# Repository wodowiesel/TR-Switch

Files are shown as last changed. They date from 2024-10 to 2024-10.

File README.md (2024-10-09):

# TR-Switch

The TX/RX-switch is a tool for signal sensitive or PTT switching for HAM radios incl. pcb schematics.

## DISCLAIMERS

**This is still "work-in-progress (WIP)" so I do NOT take any kind of responsibility for damages/data losses!**

**You can use this at your own risk without guarantees and put device on non conductive surface or enclosure!**

If you like the new design yo are free to share it!

Have fun :)

## HARDWARE

- 1x Custom PCB by WodoWiesel

- 1x USB-X cable for power supply

- 1x THT-SPDT relay +5V

- 3x THT-BNC female socket connector

- 1x THT-1N4001 flyback suppression diode

- 1x THT-2N3904 (TO-92) BJT transistor

- 3x THT-LED green+orange+red (tx/rx/pwr-indicator)

- 2x THT variable resistors 3-pin (~50-1kOhm)

- 1x THT-3.5mm socket (optional)

- 1x cable for PTT (optional)

- 1x enclosure/box (recommended)

- 1x Soldering iron

- Solder + flux + IPA

## SOFTWARE

No need for that.

## HOW TO USE

1. set up antenna, LNA, Transceiver and cables & adapters

2. connect PTT (optional)

3. turn on +5V power supply

4. Have Fun 73

## CREDITS

:copyright: 10/10/2023 WodoWiesel

Github (https://github.com/wodowiesel/)

Twitch (https://www.twitch.com/wodowiesel/)

Instagram (https://www.instagram.com/wodowiesel/)

YT (https://www.youtube.com/@wodowiesel/)

E-Mail (wodowiesel@quantentunnel.de)

The new design was checked by the electrical engineer theBrutzler (https://github.com/theBrutzler/)

The new optimized PCB was designed with free KiCAD software (https://www.kicad.org/)

:heavy_exclamation_mark: The PCB should be produced at a manufacturer

(like PCBWay or similar) with the RoHS lead-free option for environmental protection.

## LICENSES

- Hardware

CERN Open Hardware License Version 2 - Weakly Reciprocal

Short identifier CERN-OHL-W-2.0

[LICENSE Source](https://spdx.org/licenses/CERN-OHL-W-2.0.html)

- Software

This work is licensed under a Creative Commons Attribution-NonCommercial 3.0 Unported License.

[CCANC](http://creativecommons.org/licenses/by-nc/3.0/)

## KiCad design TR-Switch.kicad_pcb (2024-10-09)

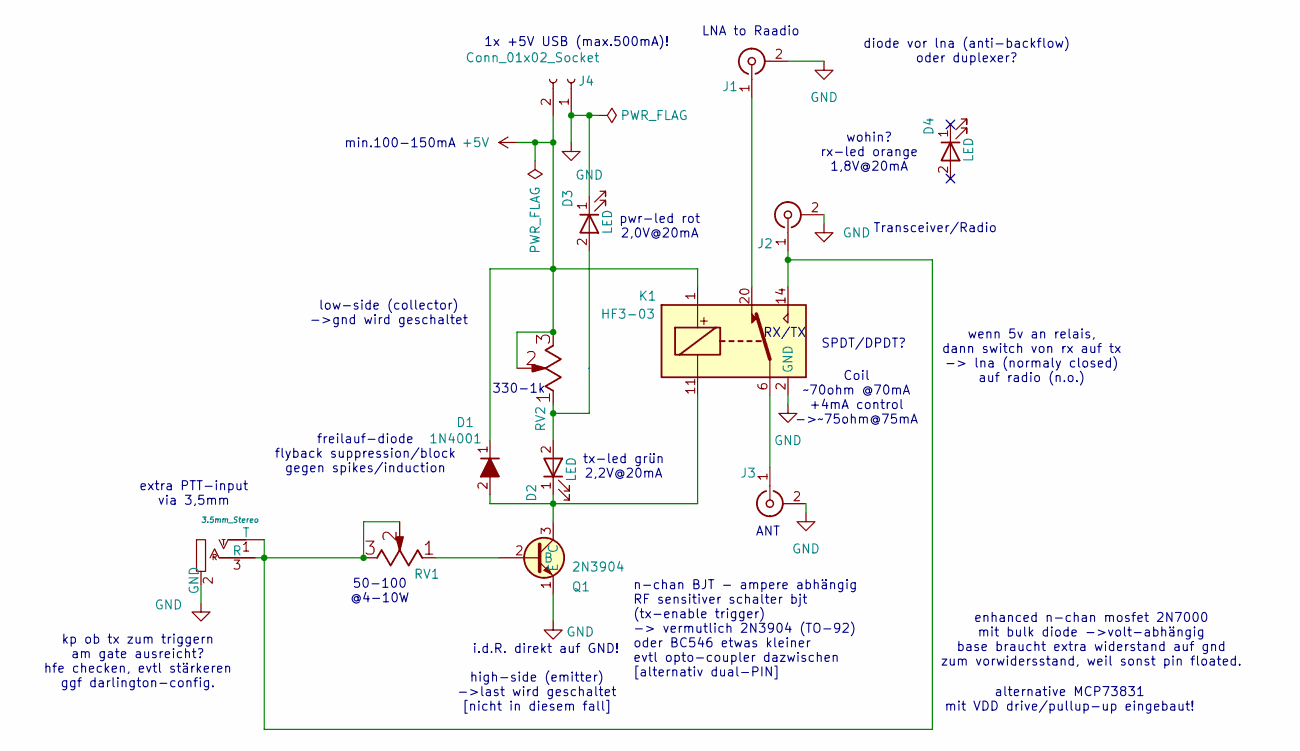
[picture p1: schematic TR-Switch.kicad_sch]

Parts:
D1: 1N4001; D_DO-41_SOD81_P7.62mm_Horizontal
D2, D3, D4: LED; LED_D5.0mm
J1, J2: Conn_Coaxial; SMA_Amphenol_132289_EdgeMount
J3: Conn_Coaxial; BNC_TEConnectivity_1478035_Horizontal
J4: Conn_01x02_Socket; PinSocket_1x02_P2.54mm_Vertical
J5: 3.5mm_Stereo_SymSmall_0.05; Jack_3.5mm_CUI_SJ1-3533NG_Horizontal-wodo; Part Number WQP-WQP419GR
K1: HF3-03; Relay_SPDT_AXICOM_HF3Series_75ohms_Pitch1.27mm
Q1: 2N3904; TO-92_Inline_Wide_EBC
RV1: 50Ohm; Potentiometer_Bourns_3386C_Horizontal
RV2: 1kOhm; Potentiometer_Bourns_3386C_Horizontal

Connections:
+5V: D1.1 (K), J4.2, K1.1, RV2.2 (b), RV2.3 (c)
GND: D3.1 (K), J1.2 (Ext), J2.2 (Ext), J3.2 (Ext), J4.1, J5.2 (GND), K1.2 (GND), K1.5 (GND), K1.7 (GND), K1.10 (GND), K1.12 (GND), K1.13 (GND), K1.15 (GND), K1.17 (GND), K1.19 (GND), K1.21 (GND), K1.22 (GND), Q1.1 (E)
unnamed: D1.2 (A), D2.1 (K), K1.11, Q1.3 (C)
unnamed: D2.2 (A), D3.2 (A), RV2.1 (a)
unnamed: J1.1 (In), K1.20
unnamed: J2.1 (In), J5.1 (T), J5.3 (R), K1.14, RV1.2 (b), RV1.3 (c)
unnamed: J3.1 (In), K1.6
unnamed: Q1.2 (B), RV1.1 (a)

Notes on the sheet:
Transceiver/Radio
high-side (emitter) ->last wird geschaltet [nicht in diesem fall]
alternative MCP73831 mit VDD drive/pullup-up eingebaut!
SPDT/DPDT?
diode vor lna (anti-backflow) oder duplexer?
wenn 5v an relais, dann switch von rx auf tx -> lna (normaly closed) auf radio (n.o.)
tx-led grün 2,2V@20mA
50-100 @4-10W
freilauf-diode flyback suppression/block gegen spikes/induction
enhanced n-chan mosfet 2N7000 mit bulk diode ->volt-abhängig base braucht extra widerstand auf gnd zum vorwidersstand, weil sonst pin floated.
n-chan BJT - ampere abhängig RF sensitiver schalter bjt (tx-enable trigger) -> vermutlich 2N3904 (TO-92) oder BC546 etwas kleiner evtl opto-coupler dazwischen [alternativ dual-PIN]
wohin? rx-led orange 1,8V@20mA
extra PTT-input via 3,5mm
330-1k
LNA to Raadio
i.d.R. direkt auf GND!
Coil ~70ohm @70mA +4mA control ->~75ohm@75mA
min.100-150mA
RX/TX
1x +5V USB (max.500mA)!
low-side (collector) ->gnd wird geschaltet
pwr-led rot 2,0V@20mA
kp ob tx zum triggern am gate ausreicht? hfe checken, evtl stärkeren ggf darlington-config.
ANT

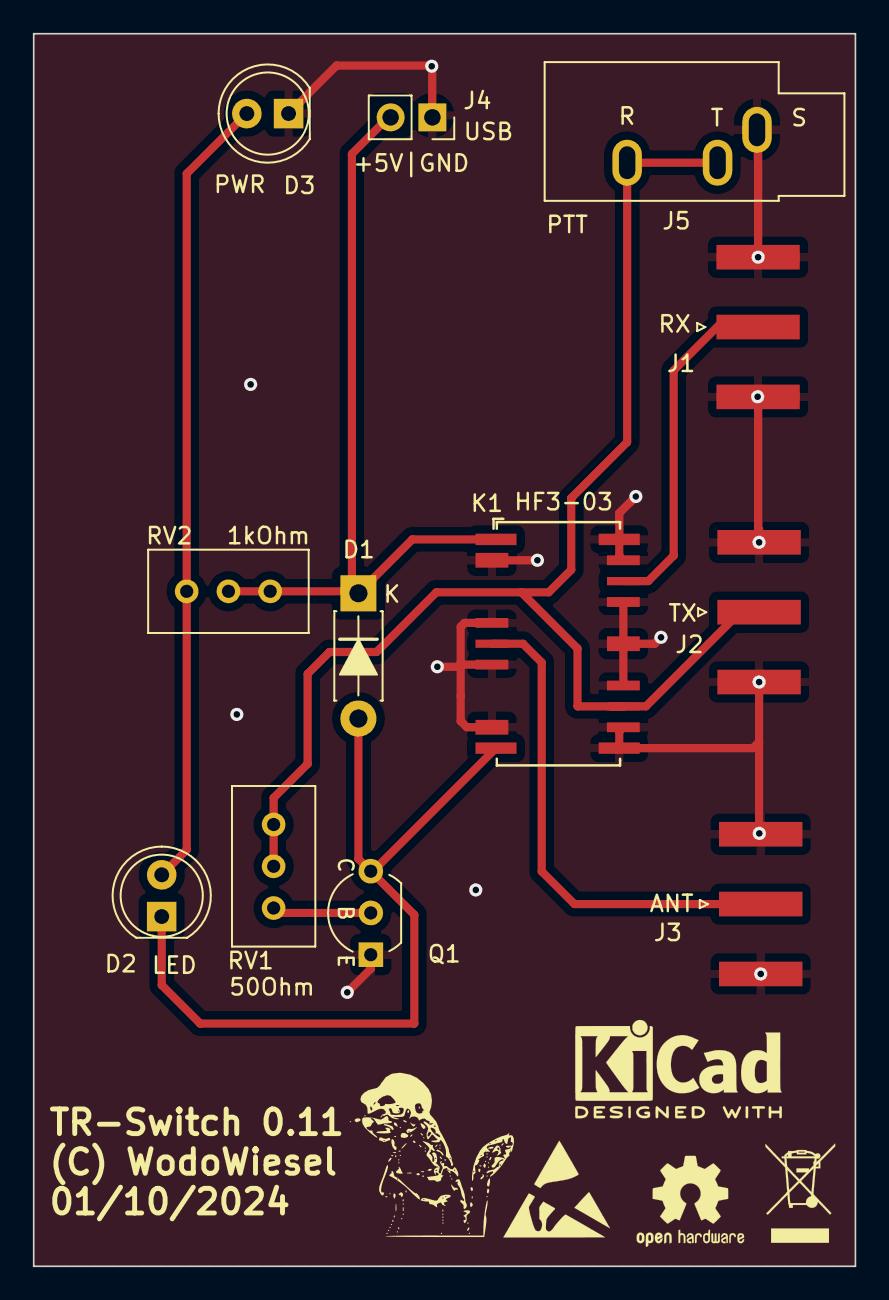
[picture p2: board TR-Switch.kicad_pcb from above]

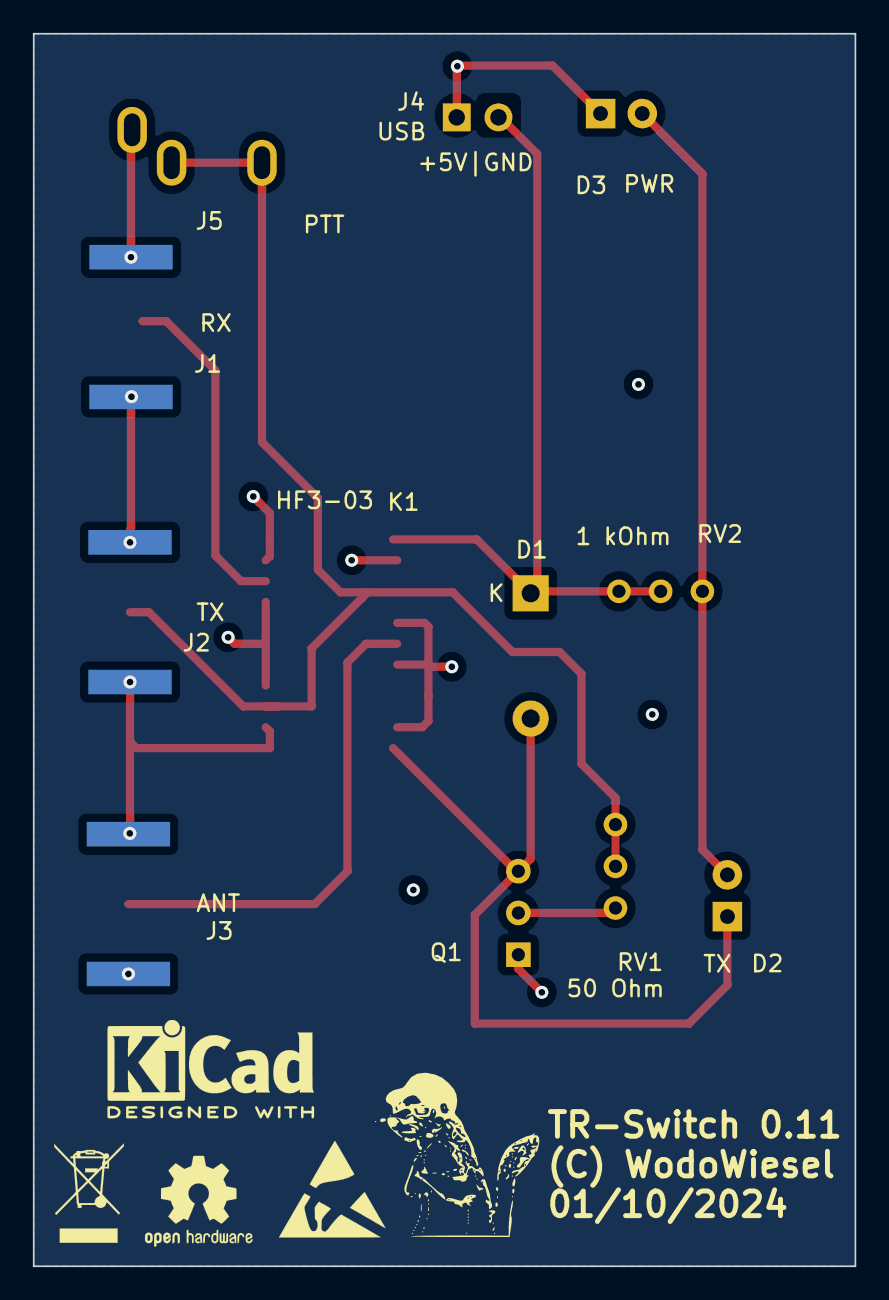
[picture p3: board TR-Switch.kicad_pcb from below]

Board: 2 copper layers, 50.0 x 75.0 mm, 22 parts (5 on the bottom side), 8 nets.

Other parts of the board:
G1, G11: LOGO; wiesel-logo-kicad-back-white
REF1, REF11: ESD-Logo_6.6x6mm_SilkScreen
REF2, REF22: OSHW-Logo2_7.3x6mm_SilkScreen
REF3, REF33: WEEE-Logo_4.2x6mm_SilkScreen
REF4, REF44: KiCad-Logo2_5mm_SilkScreen

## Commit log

2024-06-09 init
    init
    [PTT.kicad_sch, TR-Switch.kicad_pcb, TR-Switch.kicad_sch]
2024-10-09 -docu + comments -new layout
    [PTT.kicad_sch, TR-Switch.kicad_pcb, TR-Switch.kicad_sch]
